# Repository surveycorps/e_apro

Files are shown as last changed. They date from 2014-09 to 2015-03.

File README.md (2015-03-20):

e_apro
======

The electrical subsytems schematics, BOM, board files
- usb_hub is a 7 port usb hub based off of TI's TUSB2077A
- audio is a usb audio codec based off the PCM2912A
- gps is a usb powered gps module based off the Jupiter SE880
- screen is a hdmi to tft screen converter using TFP401A
- motor is a motor driver with F2V converters
- powers provides power regulator based off LM3478
- apro_lib contains all the custom symbols and footprints used
- eagle contains the files for connecting the various breakoutboards

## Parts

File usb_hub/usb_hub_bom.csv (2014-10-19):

Item | Qty | Reference(s) | Value | LibPart | Footprint | Datasheet
1 | 1 | BT1 | BATTERY | device:BATTERY | Pin_Headers:Pin_Header_Straight_1x02
2 | 2 | C1, C2 | 1uF | device:C | SMD_Packages:SMD-0603
3 | 14 | C10, C11, C12, C13, C14, C15, C16, C17, C18, C20, C21, C22, C7, C8 | 22pF | device:Csmall | SMD_Packages:SMD-0603
4 | 3 | C19, C32, C6 | 4.7uF | device:C | SMD_Packages:SMD-0603
5 | 2 | C23, C24 | 22pF | device:C | SMD_Packages:SMD-0603
6 | 7 | C25, C26, C29, C33, C34, C35, C36 | 100uF | device:Csmall | SMD_Packages:SMD-1210
7 | 7 | C27, C28, C31, C37, C38, C39, C40 | .1uF | device:Csmall | SMD_Packages:SMD-0603
8 | 3 | C3, C30, C9 | .1uF | device:C | SMD_Packages:SMD-0603
9 | 2 | C4, C5 | 33pF | device:Csmall | SMD_Packages:SMD-0603
10 | 4 | D1, D2, D4, D6 | LED(G) | device:LED | LEDs:LED-0603
11 | 2 | D3, D5 | LED | device:LED | LEDs:LED-0603
12 | 1 | F1 | FUSE | device:FUSE | SMD_Packages:SMD-0603
13 | 2 | JP1, JP2 | JUMPER | device:JUMPER | Connect:GS2
14 | 8 | L1, L2, L3, L4, L5, L6, L7, L8 | FERRITE | usb_hub:FERRITE | usb_hub:FB-28F0121
15 | 1 | P1 | CONN_01X02 | conn:CONN_01X02 | Pin_Headers:Pin_Header_Straight_1x02
16 | 21 | R1, R2, R21, R22, R23, R24, R25, R26, R27, R28, R29, R3, R30, R31, R32, R33, R34, R4, R5, R6, R7 | 15k | device:R | SMD_Packages:SMD-0603
17 | 16 | R10, R11, R12, R13, R14, R15, R16, R17, R18, R19, R20, R35, R36, R38, R41, R9 | 27 | device:R | SMD_Packages:SMD-0603
18 | 6 | R37, R39, R40, R42, R44, R45 | 510 | device:R | SMD_Packages:SMD-0603
19 | 2 | R43, R8 | 1.5k | device:R | SMD_Packages:SMD-0603
20 | 2 | U1, U2 | TPS2044B | usb_hub:TPS2044B | Housings_SOIC:SOIC-16_3.9x9.9mm_Pitch1.27mm
21 | 7 | U10, U13, U14, U15, U16, U8, U9 | USB_A_FEMALE | usb_hub:USB_A_FEMALE | ab2_usb:AB2_USB_MICRO_SMD
22 | 4 | U11, U12, U6, U7 | SN75240 | usb_hub:SN75240 | usb_hub:TSSOP8
23 | 1 | U3 | TUSB2077A | usb_hub:TUSB2077A | Housings_QFP:TQFP-48_7x7mm_Pitch0.5mm
24 | 1 | U4 | TPS76333 | usb_hub:TPS76333 | SMD_Packages:SOT-23-5
25 | 1 | U5 | USB_A_MALE | usb_hub:USB_A_MALE | ab2_usb:AB2_USB_MICRO_SMD
26 | 1 | X1 | 6 MHz | device:CRYSTAL | usb_hub:FOX6MHZ

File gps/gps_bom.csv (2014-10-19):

Item | Qty | Reference(s) | Value | LibPart | Footprint | Datasheet
1 | 5 | C1, C10, C11, C3, C5 | .1uF | device:Csmall | SMD_Packages:SMD-0603
2 | 1 | C2 | 18pF | device:Csmall | SMD_Packages:SMD-0603
3 | 1 | C4 | 22pF | device:Csmall | SMD_Packages:SMD-0603
4 | 2 | C6, C7 | 1uF | device:Csmall | SMD_Packages:SMD-0603
5 | 2 | C8, C9 | 10uF | device:Csmall | SMD_Packages:SMD-0603
6 | 1 | D1 | LED(G) | device:LED | LEDs:LED-0603
7 | 7 | JP1, JP2, JP3, JP4, JP5, JP6, JP7 | JUMPER | device:JUMPER | Connect:GS2
8 | 1 | P1 | PWR | conn:CONN_01X02 | Pin_Headers:Pin_Header_Straight_1x02
9 | 1 | P2 | CTL | conn:CONN_01X02 | Pin_Headers:Pin_Header_Straight_1x02
10 | 1 | P3 | UART | conn:CONN_01X02 | Pin_Headers:Pin_Header_Straight_1x02
11 | 1 | R1 | 510 | device:R | SMD_Packages:SMD-0603
12 | 2 | R2, R3 | 100k | device:R | SMD_Packages:SMD-0603
13 | 3 | R4, R5, R7 | 10k | device:R | SMD_Packages:SMD-0603
14 | 1 | R6 | 6k | device:R | SMD_Packages:SMD-0603
15 | 1 | U1 | USB_A_FEMALE | gps-cache:USB_A_FEMALE | ab2_usb:AB2_USB_MICRO_SMD
16 | 1 | U2 | TXS0102 | gps:TXS0102 | gps:TXS0102
17 | 1 | U3 | SE880 | gps:SE880 | gps:SE880
18 | 1 | U4 | ABS25 | gps:ABS25 | gps:ABS25
19 | 1 | U5 | SGP25C | gps:SGP25C | gps:SGP25C
20 | 1 | U6 | KT2520 | gps:KT2520 | gps:KT2520
21 | 1 | U7 | TPS76333 | gps:TPS76318 | SMD_Packages:SOT-23-5
22 | 1 | U8 | TPS76318 | gps:TPS76318 | SMD_Packages:SOT-23-5

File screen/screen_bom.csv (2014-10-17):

Item | Qty | Reference(s) | Value | LibPart | Footprint | Datasheet
1 | 4 | C1, C2, C3, C4 | 22uF | device:Csmall | SMD_Packages:SMD-0603
2 | 1 | C10 | 0.22uF | device:Csmall | SMD_Packages:SMD-0603
3 | 2 | C11, C13 | 10uF | device:Csmall | SMD_Packages:SMD-1206
4 | 6 | C12, C15, C5, C6, C7, C8 | 0.1uF | device:Csmall | SMD_Packages:SMD-0603
5 | 1 | C14 | 4.7uF | device:Csmall | SMD_Packages:SMD-0603
6 | 1 | C9 | 1uF | device:Csmall | SMD_Packages:SMD-0603
7 | 1 | D1 | DIODESCH | device:DIODESCH | SCREEN:SOD323
8 | 1 | D2 | GREEN | device:LED | LEDs:LED-0603
9 | 1 | JP1 | NHD | device:JUMPER | Connect:GS2
10 | 1 | JP2 | BD | device:JUMPER | Connect:GS2
11 | 1 | JP3 | HVT | device:JUMPER | Connect:GS2
12 | 1 | JP4 | ST+ | device:JUMPER | Connect:GS2
13 | 1 | JP5 | ST- | device:JUMPER | Connect:GS2
14 | 1 | L1 | 22uH | device:INDUCTOR | SCREEN:VLCF5020
15 | 1 | P1 | CONN_01X08 | conn:CONN_01X08 | Pin_Headers:Pin_Header_Straight_1x08
16 | 2 | Q1, Q2 | N_MOS | screen:N_MOS | SMD_Packages:SOT-23
17 | 3 | R1, R2, R3 | 4.7k | screen:Rsmall | SMD_Packages:SMD-0603
18 | 4 | R10, R4, R8, R9 | 10k | screen:Rsmall | SMD_Packages:SMD-0603
19 | 1 | R11 | 1k | screen:Rsmall | SMD_Packages:SMD-0603
20 | 1 | R12 | 510R | screen:Rsmall | SMD_Packages:SMD-0603
21 | 1 | R5 | 3.32R | screen:Rsmall | SMD_Packages:SMD-0603
22 | 1 | R6 | 4.99R | screen:Rsmall | SMD_Packages:SMD-0603
23 | 1 | R7 | 10R | screen:Rsmall | SMD_Packages:SMD-0603
24 | 1 | U1 | uHDMI | screen:uHDMI | SCREEN:uHDMI
25 | 1 | U2 | TFP401A | screen:TFP401A | SCREEN:TFP401A
26 | 1 | U3 | TPS76333 | screen:TPS76333 | SMD_Packages:SOT-23-5
27 | 1 | U4 | TSP61161 | screen:TSP61161 | SCREEN:TSP61161
28 | 1 | U5 | M93C46 | usb_hub:M93C46 | SCREEN:TSSOP8
29 | 1 | U6 | HVT-4.3 | screen:HVT-4.3 | SCREEN:40_PIN
30 | 1 | U7 | NHD-5.0 | screen:NHD-5.0 | SCREEN:40_PIN
31 | 1 | USB1 | AB2_USB | ab2_usb:AB2_USB | MICRO_USB:AB2_USB_MICRO_SMD

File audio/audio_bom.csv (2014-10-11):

Item | Qty | Reference(s) | Value | LibPart | Footprint | Datasheet
1 | 6 | C1, C11, C3, C4, C5, C6 | 1uF | device:C | SMD_Packages:SMD-0603
2 | 1 | C10 | 2.2uF | device:C | SMD_Packages:SMD-0603
3 | 6 | C12, C17, C24, C25, C31, C9 | 0.1uF | device:C | SMD_Packages:SMD-0603
4 | 1 | C13 | 3u3 | device:C | SMD_Packages:SMD-0603
5 | 2 | C14, C15 | 100pF | device:C | SMD_Packages:SMD-0603
6 | 2 | C16, C8 | 22pF | device:C | SMD_Packages:SMD-0603
7 | 4 | C18, C23, C26, C32 | 10uF | device:C | SMD_Packages:SMD-0603
8 | 4 | C19, C21, C28, C30 | 1nF | device:C | SMD_Packages:SMD-0603
9 | 2 | C2, C7 | 100uF | device:C | SMD_Packages:SMD-1206
10 | 4 | C20, C22, C27, C29 | 0.47uF | device:C | SMD_Packages:SMD-0603
11 | 1 | D1 | RED | device:LED | LEDs:LED-0603
12 | 2 | D2, D3 | GREEN | device:LED | LEDs:LED-0603
13 | 2 | JP1, JP2 | JUMPER | device:JUMPER | Connect:GS2
14 | 1 | JP3 | HGS | device:JUMPER | Connect:GS2
15 | 1 | JP4 | LGS | device:JUMPER | Connect:GS2
16 | 1 | L1 | 1uH | device:INDUCTOR | SMD_Packages:SMD-0603
17 | 2 | P1, P3 | CONN_02X01 | conn:CONN_02X01 | Pin_Headers:Pin_Header_Straight_2x01
18 | 1 | P2 | CONN_01X04 | conn:CONN_01X04 | Pin_Headers:Pin_Header_Straight_1x04
19 | 3 | R1, R2, R8 | 1K5 | device:R | SMD_Packages:SMD-0603
20 | 1 | R10 | 1M | device:R | SMD_Packages:SMD-0603
21 | 1 | R11 | 510R | device:R | SMD_Packages:SMD-0603
22 | 4 | R3, R4, R7, R9 | 3K3 | device:R | SMD_Packages:SMD-0603
23 | 2 | R5, R6 | 30R | device:R | SMD_Packages:SMD-0603
24 | 1 | SP1 | RIGHT | device:SPEAKER | Connect:PINHEAD1-2
25 | 1 | SP2 | LEFT | device:SPEAKER | Connect:PINHEAD1-2
26 | 1 | U1 | PCM2912A | audio:PCM2912A | SMD_Packages:TQFP-32
27 | 1 | U2 | MIC | audio:MIC | MIC:MIC
28 | 4 | U3, U4, U6, U7 | FB | audio:FB | MIC:FB-28F0121
29 | 1 | U5 | NAU8223 | audio:NAU8223 | MIC:QFN20
30 | 1 | X1 | 6MHz | device:CRYSTAL | MIC:FOX6MHZ

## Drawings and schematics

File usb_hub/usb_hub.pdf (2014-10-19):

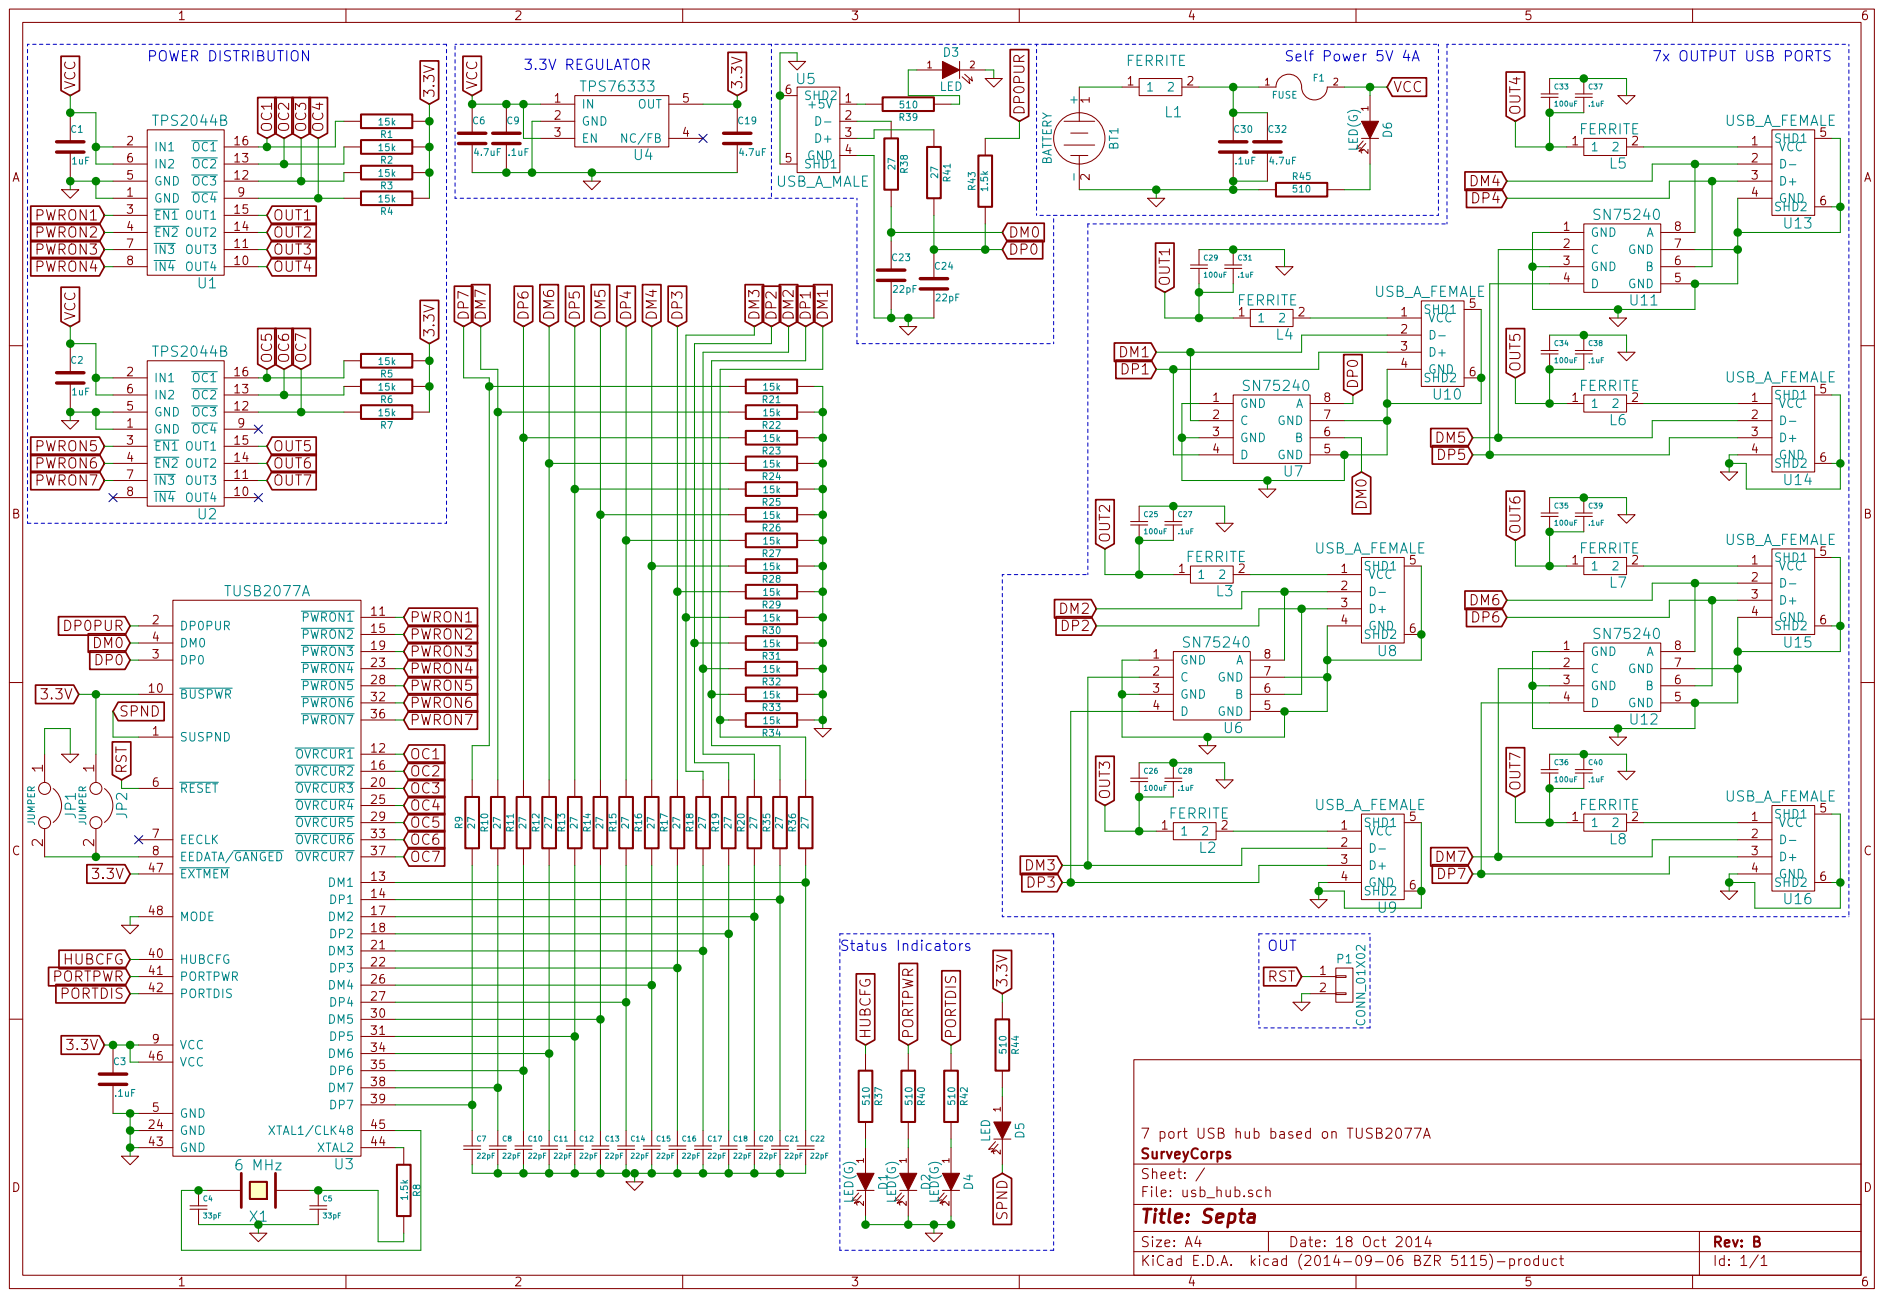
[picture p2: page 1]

1 2 D1 LED(G)1 2 D2 LED(G)1 2 D4 LED(G) 510 R37 510 R40 510 R42 HUBCFG PORTPWR PORTDIS

7 port USB hub based on TUSB2077A
File: usb_hub.sch Sheet: / SurveyCorps

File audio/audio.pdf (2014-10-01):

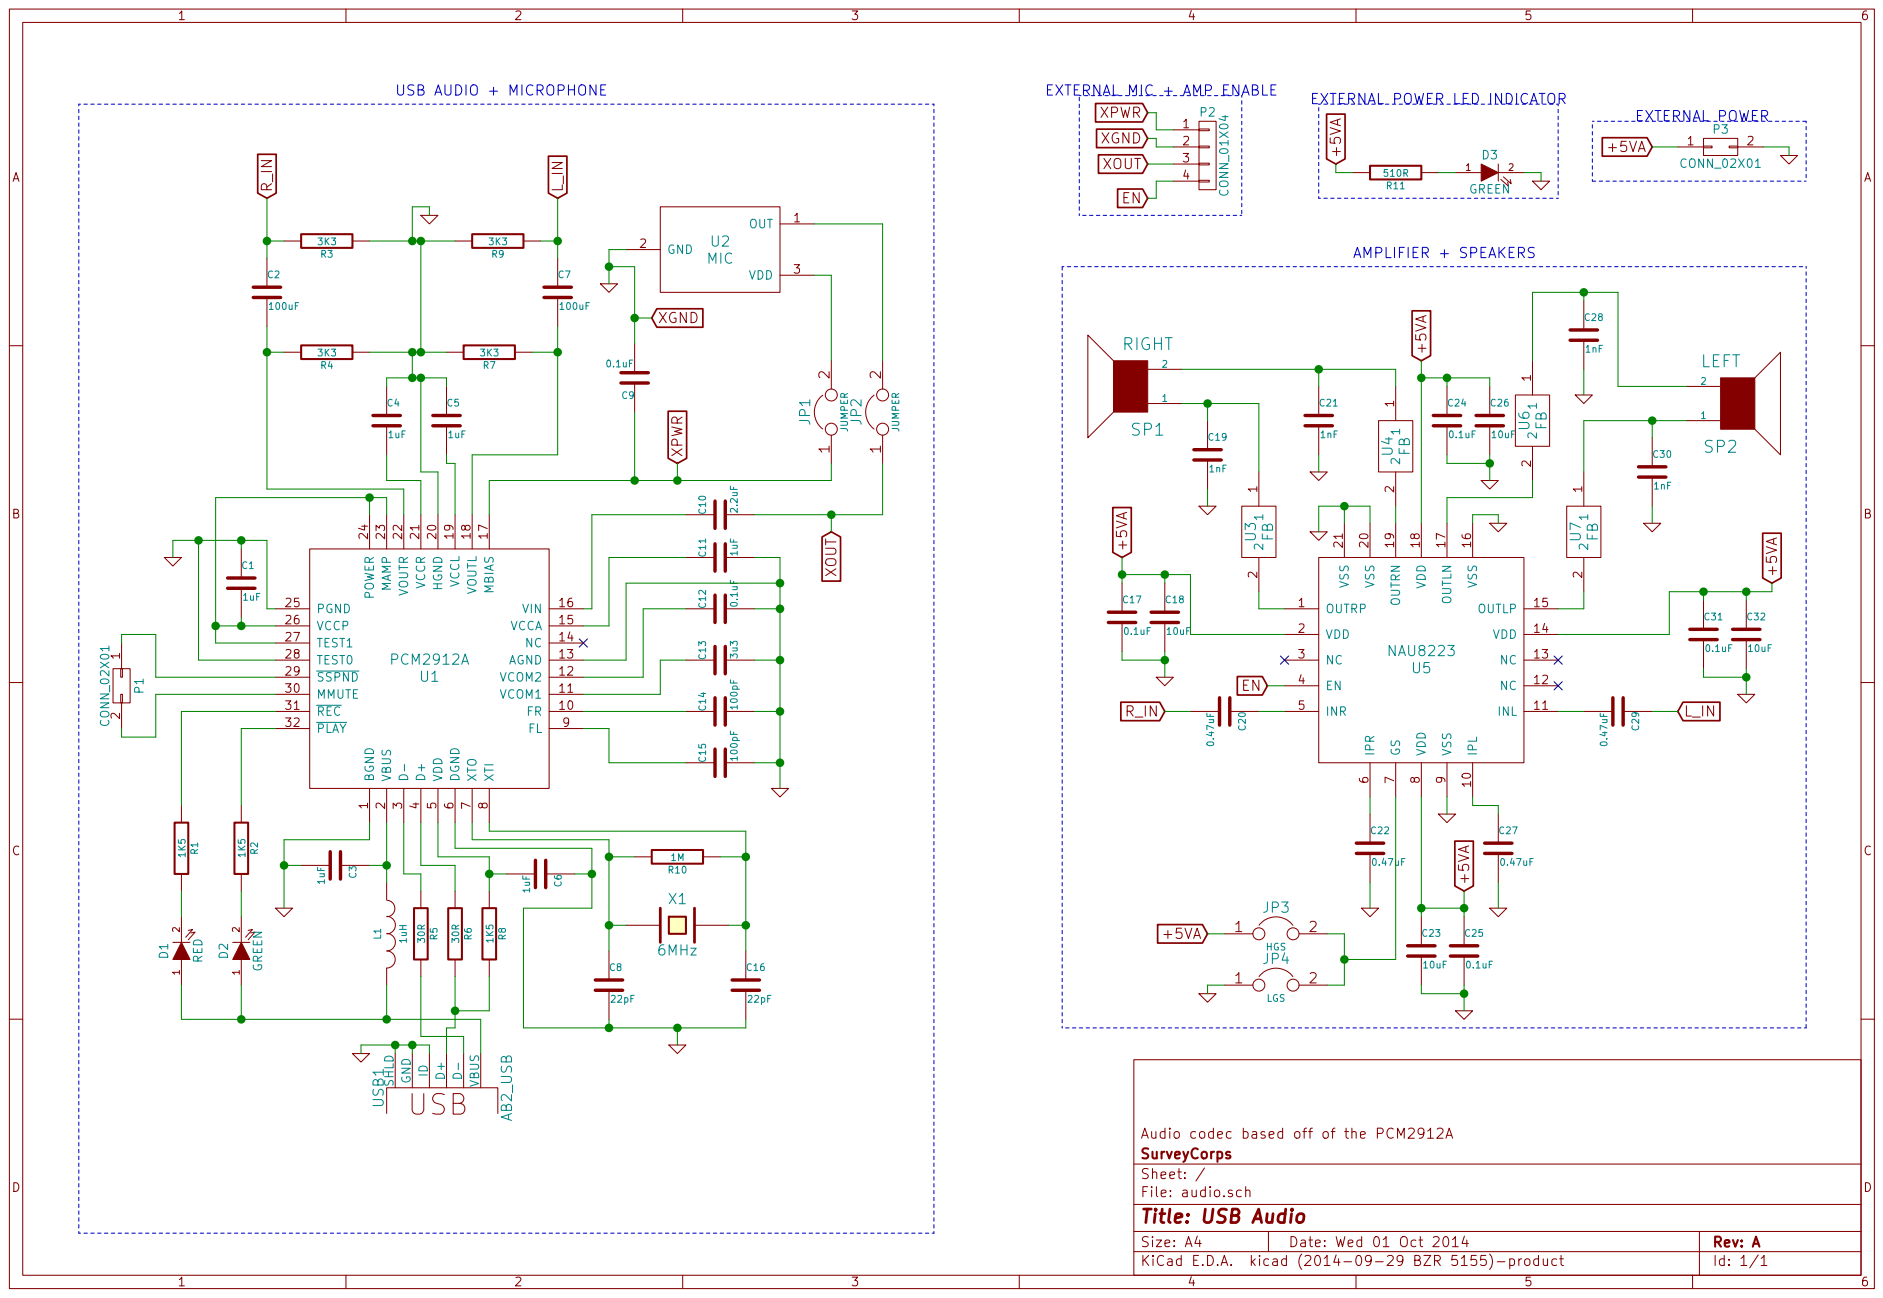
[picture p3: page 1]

EXTERNAL MIC + AMP ENABLE

510R EXTERNAL POWER LED INDICATOR

File: audio.sch Sheet: / SurveyCorps Audio codec based off of the PCM2912A

Id: 1/1 Title: USB Audio

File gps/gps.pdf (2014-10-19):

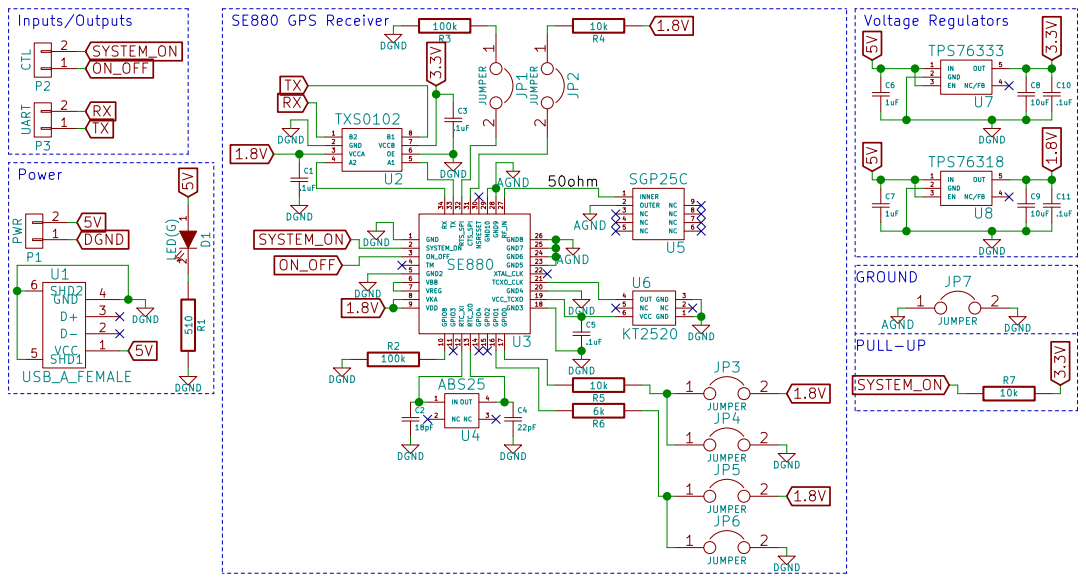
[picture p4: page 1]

GPS Receiver Based on the Jupiter SE880
File: gps.sch Sheet: / SurveyCorps

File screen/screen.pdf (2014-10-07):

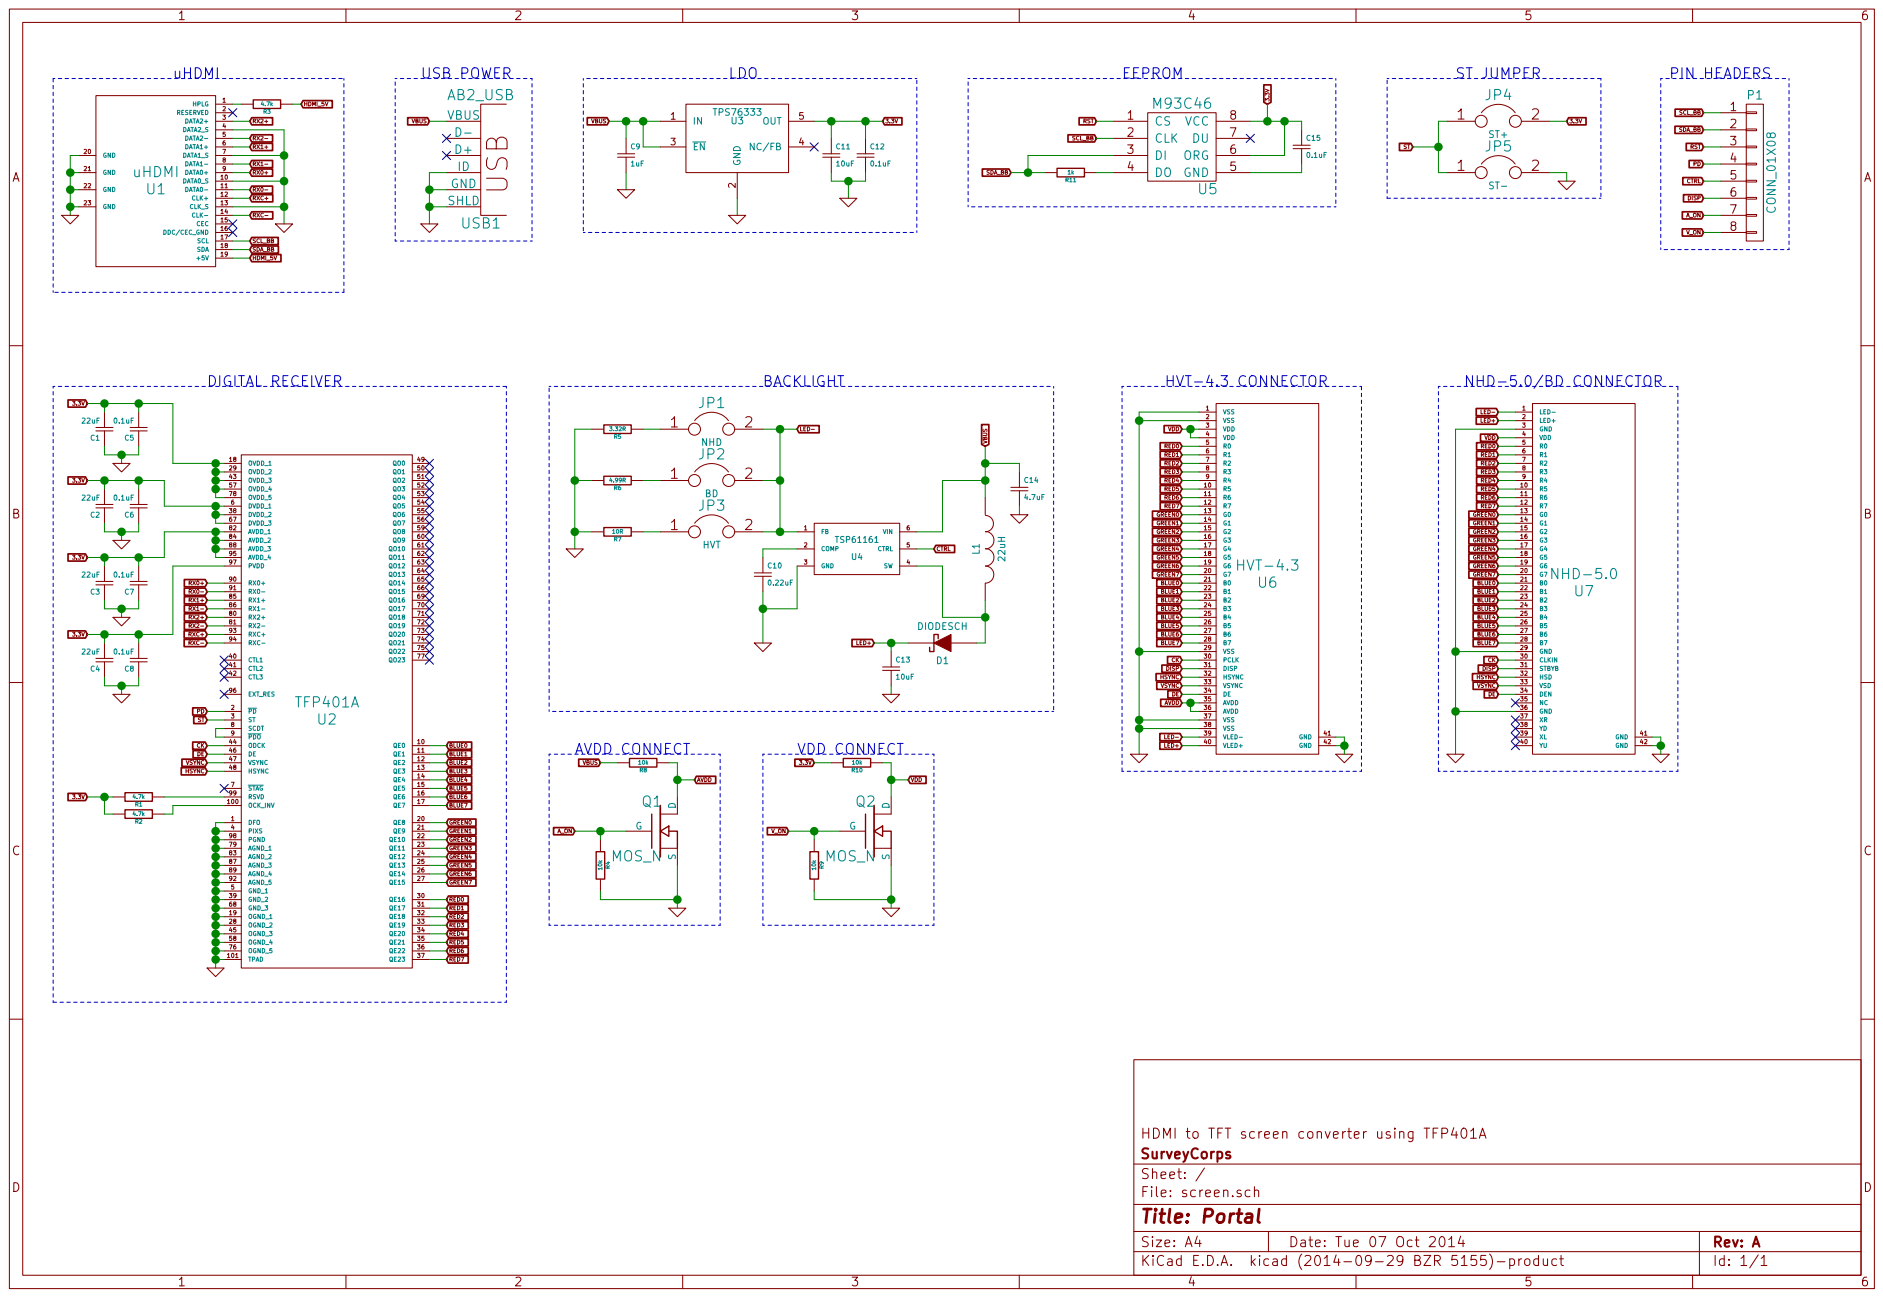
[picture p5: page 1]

2 EN 3 NC/FB 4 OUT 5 U3 TPS76333

HDMI to TFT screen converter using TFP401A
Id: 1/1 Title: Portal File: screen.sch Sheet: / SurveyCorps

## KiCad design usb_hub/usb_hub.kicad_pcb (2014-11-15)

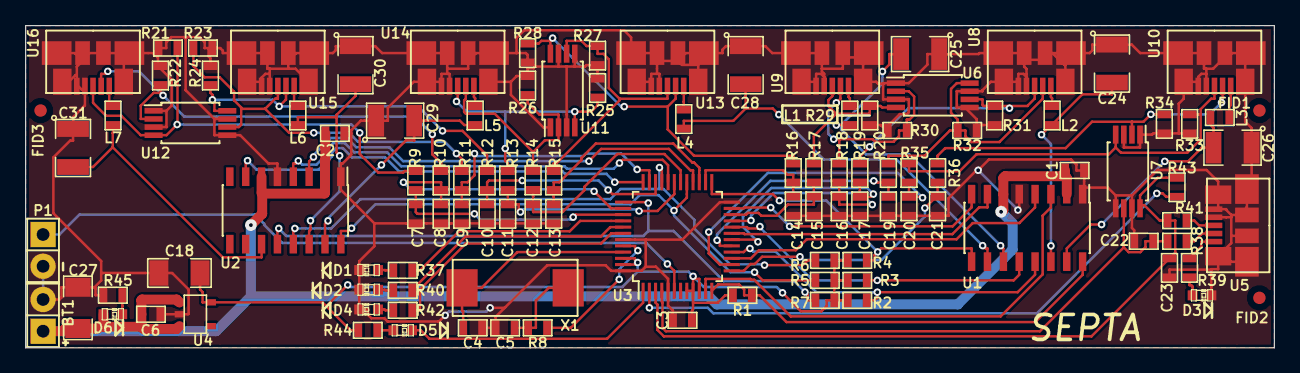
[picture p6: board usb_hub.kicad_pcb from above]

Board: 2 copper layers, 100.0 x 25.8 mm, 111 parts (0 on the bottom side), 79 nets.

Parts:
BT1: BATTERY; Pin_Header_Straight_1x02
C1, C2, C6: 1uF; SMD-0603
C3: .1uF; SMD-0603
C4, C5: 33pF; SMD-0603
C7, C8, C9, C10, C11, C12, C13, C14, C15, C16, C17, C19, C20, C21, C22, C23: 22pF; SMD-0603
C18, C27: 10uF; SMD-1206
C24, C25, C26, C28, C29, C30, C31: 100uF; SMD-1210
D1, D2, D3, D4, D5, D6: LED; LED-0603
FID1, FID2, FID3: VAL**; SBA_FID
L1, L2, L3, L4, L5, L6, L7: FERRITE; SMD-0603
P1: CONN_01X02; Pin_Header_Straight_1x02
R1, R2, R3, R4, R5, R6, R7, R21, R22, R23, R24, R25, R26, R27, R28, R29, R30, R31, R32, R33, R34: 15k; SMD-0603
R8, R43: 1.5k; SMD-0603
R9, R10, R11, R12, R13, R14, R15, R16, R17, R18, R19, R20, R35, R36, R38, R41: 30; SMD-0603
R37, R39, R40, R42, R44, R45: 1k; SMD-0603
U1, U2: TPS2044B; SOIC-16_3.9x9.9mm_Pitch1.27mm
U3: TUSB2077A; TQFP-48_7x7mm_Pitch0.5mm
U4: TPS76333; SOT-23-5
U5: USB_A_MALE; MICRO_USB
U6, U7, U11, U12: SN75240; TSSOP-8_4.4x3mm_Pitch0.65mm
U8, U9, U10, U13, U14, U15, U16: USB_MICRO_OUT; MICRO_USB
X1: 6 MHz; FOX6MHZ

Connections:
3.3V: C3.1, C18.1, R1.1, R2.1, R3.1, R4.1, R5.1, R6.1, R7.1, R44.1, U3.8, U3.9, U3.10, U3.46, U3.47, U4.5
DM0: C22.1, R38.1, U3.4, U7.6
DM1: R34.2, R36.2, U7.2, U10.2
DM2: R20.2, R32.2, U6.8, U8.2
DM3: R18.2, R30.2, U6.2, U9.2
DM4: R16.2, R28.2, U11.8, U13.2
DM5: R14.2, R26.2, U11.2, U14.2
DM6: R12.2, R24.2, U12.8, U15.2
DM7: R10.2, R22.2, U12.2, U16.2
DP0: C23.1, R41.1, R43.2, U3.3, U7.8
DP0PUR: R43.1, U3.2
DP1: R33.2, R35.2, U7.4, U10.3
DP2: R19.2, R31.2, U6.6, U8.3
DP3: R17.2, R29.2, U6.4, U9.3
DP4: R15.2, R27.2, U11.6, U13.3
DP5: R13.2, R25.2, U11.4, U14.3
DP6: R11.2, R23.2, U12.6, U15.3
DP7: R9.2, R21.2, U12.4, U16.3
GND: BT1.2, C1.2, C2.2, C3.2, C4.2, C5.2, C6.2, C7.2, C8.2, C9.2, C10.2, C11.2, C12.2, C13.2, C14.2, C15.2, C16.2, C17.2, C18.2, C19.2, C20.2, C21.2, C22.2, C23.2, C24.1, C25.1, C26.1, C27.2, C28.1, C29.1, C30.1, C31.1, D1.2, D2.2, D3.2, D4.2, P1.2, R21.1, R22.1, R23.1, R24.1, R25.1, R26.1, R27.1, R28.1, R29.1, R30.1, R31.1, R32.1, R33.1, R34.1, R45.1, U1.1, U1.5, U2.1, U2.5, U3.5, U3.24, U3.43, U3.48, U4.2, U5.4, U5.5, U5.6, U6.1, U6.3, U6.5, U6.7, U7.1, U7.3, U7.5, U7.7, U8.4, U8.5, U8.6, U9.4, U9.5, U9.6, U10.4, U10.5, U10.6, U11.1, U11.3, U11.5, U11.7, U12.1, U12.3, U12.5, U12.7, U13.4, U13.5, U13.6, U14.4, U14.5, U14.6, U15.4, U15.5, U15.6, U16.4, U16.5, U16.6
HUBCFG: R37.1, U3.40
unnamed: C4.1, U3.45, X1.2
unnamed: C5.1, R8.2, X1.1
unnamed: C7.1, R9.1, U3.39
unnamed: C8.1, R10.1, U3.38
unnamed: C9.1, R11.1, U3.35
unnamed: C10.1, R12.1, U3.34
unnamed: C11.1, R13.1, U3.31
unnamed: C12.1, R14.1, U3.30
unnamed: C13.1, R15.1, U3.27
unnamed: C14.1, R16.1, U3.26
unnamed: C15.1, R17.1, U3.22
unnamed: C16.1, R18.1, U3.21
unnamed: C17.1, R19.1, U3.18
unnamed: C19.1, R20.1, U3.17
unnamed: C20.1, R35.1, U3.14
unnamed: C21.1, R36.1, U3.13
unnamed: D1.1, R37.2
unnamed: D2.1, R40.2
unnamed: D3.1, R39.1
unnamed: D4.1, R42.2
unnamed: D5.1, R44.2
unnamed: D6.2, R45.2
unnamed: L1.2, U9.1
unnamed: L2.2, U8.1
unnamed: L3.2, U10.1
unnamed: L4.2, U13.1
unnamed: L5.2, U14.1
unnamed: L6.2, U15.1
unnamed: L7.2, U16.1
unnamed: R8.1, U3.44
unnamed: R38.2, U5.2
unnamed: R39.2, U5.1
unnamed: R41.2, U5.3
OC1: R1.2, U1.16, U3.12
OC2: R2.2, U1.13, U3.16
OC3: R3.2, U1.12, U3.20
OC4: R4.2, U1.9, U3.25
OC5: R5.2, U2.16, U3.29
OC6: R6.2, U2.13, U3.33
OC7: R7.2, U2.12, U3.37
OUT1: C26.2, L3.1, U1.15
OUT2: C24.2, L2.1, U1.14
OUT3: C25.2, L1.1, U1.11
OUT4: C28.2, L4.1, U1.10
OUT5: C29.2, L5.1, U2.15
OUT6: C30.2, L6.1, U2.14
OUT7: C31.2, L7.1, U2.11
PORTDIS: R42.1, U3.42
PORTPWR: R40.1, U3.41
PWRON1: U1.3, U3.11
PWRON2: U1.4, U3.15
PWRON3: U1.7, U3.19
PWRON4: U1.8, U3.23
PWRON5: U2.3, U3.28
PWRON6: U2.4, U3.32
PWRON7: U2.7, U3.36
RST: P1.1, U3.6
SPND: D5.2, U3.1
VCC: BT1.1, C1.1, C2.1, C6.1, C27.1, D6.1, U1.2, U1.6, U2.2, U2.6, U4.1, U4.3

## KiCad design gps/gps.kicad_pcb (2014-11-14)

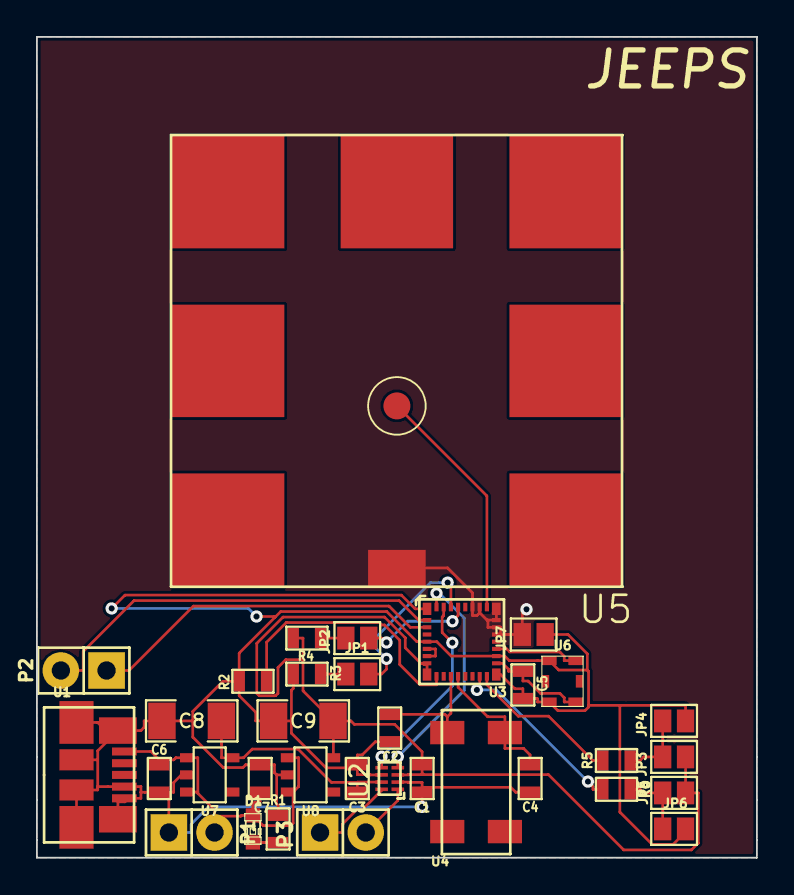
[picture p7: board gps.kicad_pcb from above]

Board: 2 copper layers, 40.0 x 45.6 mm, 34 parts (0 on the bottom side), 27 nets.

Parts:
C1, C3, C5: .1uF; SMD-0603
C2: 18pF; SMD-0603
C4: 22pF; SMD-0603
C6, C7: 1uF; SMD-0603
C8, C9: 10uF; SMD-1206
D1: LED; LED-0603
JP1, JP2, JP3, JP4, JP5, JP6, JP7: JUMPER; GS2
P1: PWR; Pin_Header_Straight_1x02
P2: CTL; Pin_Header_Straight_1x02
P3: UART; Pin_Header_Straight_1x02
R1: 1k; SMD-0603
R2, R3: 100k; SMD-0603
R4, R5: 10k; SMD-0603
R6: 6k; SMD-0603
U1: USB_A_FEMALE; MICRO_USB
U2: TXS0102
U3: SE880
U4: ABS25
U5: SGP25C
U6: KT2520
U7: TPS76333; SOT-23-5
U8: TPS76318; SOT-23-5

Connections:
1.8V: C1.1, C9.1, JP3.2, JP5.2, R4.1, U2.3, U3.8, U3.9, U8.5
3.3V: C3.1, C8.1, U2.7, U7.5
5V: C6.1, C7.1, D1.1, P1.2, U1.1, U7.1, U7.3, U8.1, U8.3
/50ohm: U3.27, U5.1
AGND: JP7.1, U3.23, U3.24, U3.25, U3.26, U3.28, U3.29, U5.2
DGND: C1.2, C2.2, C3.2, C4.2, C5.2, C6.2, C7.2, C8.2, C9.2, JP4.2, JP6.2, JP7.2, P1.1, R1.2, R2.2, R3.2, U1.4, U1.5, U1.6, U2.2, U2.6, U3.1, U3.5, U3.18, U3.20, U6.1, U6.3, U7.2, U8.2
unnamed: C2.1, U3.12, U4.1
unnamed: C4.1, U3.13, U4.4
unnamed: C5.1, U3.19, U6.6
unnamed: D1.2, R1.1
unnamed: JP1.1, R3.1
unnamed: JP1.2, U3.32
unnamed: JP2.1, R4.2
unnamed: JP2.2, U3.31
unnamed: JP3.1, JP4.1, R5.1
unnamed: JP5.1, JP6.1, R6.1
unnamed: R2.1, U3.10
unnamed: R5.2, U3.17
unnamed: R6.2, U3.16
unnamed: U2.4, U3.34
unnamed: U2.5, U3.33
unnamed: U3.6, U3.7
unnamed: U3.21, U6.4
ON_OFF: P2.1, U3.3
RX: P3.2, U2.1
SYSTEM_ON: P2.2, U3.2
TX: P3.1, U2.8

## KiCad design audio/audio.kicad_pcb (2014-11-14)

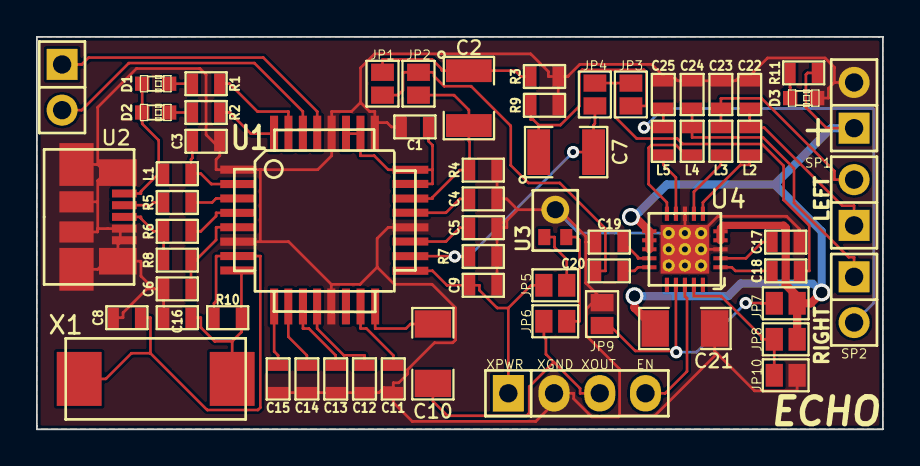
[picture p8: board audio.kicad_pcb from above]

Board: 2 copper layers, 47.0 x 21.8 mm, 64 parts (0 on the bottom side), 52 nets.

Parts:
C1, C3, C4, C5, C6, C11, C17, C18, C19, C20: 1uF; SMD-0603
C2, C7: 100uF; SMD-1210
C8, C16: 33pF; SMD-0603
C9, C12: .1uF; SMD-0603
C10, C21: 10uF; SMD-1206
C13: 3.3uF; SMD-0603
C14, C15: 100pF; SMD-0603
C22, C23, C24, C25: 1nF; SMD-0603
D1, D2, D3: GREEN; LED-0603
JP1, JP2, JP3, JP4, JP5, JP6, JP7, JP8, JP9, JP10: JUMPER; GS2
L1: 1uH; SMD-0603
L2, L3, L4, L5: FERRITE; SMD-0603
P1, P3: CONN_02X01; Pin_Header_Straight_2x01
P2: CONN_01X04; Pin_Header_Straight_1x04
R1, R2, R11: 1k; SMD-0603
R3, R4, R7, R9: 3K3; SMD-0603
R5, R6: 30R; SMD-0603
R8: 1K5; SMD-0603
R10: 1M; SMD-0603
SP1, SP2: SPEAKER; Pin_Header_Straight_2x01
U1: PCM2912A; TQFP-32
U2: USB_A_MALE; MICRO_USB
U3: MIC
U4: TPA2017D2
X1: 6MHz; FOX6MHZ

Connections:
+5VA: C21.2, JP7.1, JP8.1, P3.1, R11.2, U4.4, U4.5, U4.11, U4.12, U4.13
EN: P2.4, U4.18
L_IN: C18.2, JP3.1, JP4.2
unnamed: C1.1, U1.23, U1.24, U1.26, U1.27
unnamed: C2.1, JP1.2, R3.2
unnamed: C2.2, JP2.1, R4.2, U1.22
unnamed: C3.1, L1.1, U1.2
unnamed: C4.2, U1.21
unnamed: C5.2, U1.19
unnamed: C6.2, R8.1, U1.5
unnamed: C7.1, JP4.1, R9.1
unnamed: C7.2, JP3.2, R7.1, U1.18
unnamed: C8.1, R10.2, U1.7, X1.1
unnamed: C10.2, U1.16
unnamed: C11.1, U1.15
unnamed: C12.2, U1.12
unnamed: C13.2, U1.11
unnamed: C14.2, U1.10
unnamed: C15.2, U1.9
unnamed: C16.1, R10.1, U1.8, X1.2
unnamed: C17.1, U4.2
unnamed: C18.1, U4.1
unnamed: C19.1, U4.14
unnamed: C20.1, U4.15
unnamed: C22.2, L2.2, SP1.1
unnamed: C23.2, L3.2, SP1.2
unnamed: C24.2, L4.2, SP2.1
unnamed: C25.2, L5.2, SP2.2
unnamed: D1.1, D2.1, L1.2, U2.1
unnamed: D1.2, R1.2
unnamed: D2.2, R2.2
unnamed: D3.1, R11.1
unnamed: JP5.2, U3.3
unnamed: JP6.2, U3.1
unnamed: JP7.2, JP9.2, U4.17
unnamed: JP8.2, JP10.2, U4.19
unnamed: L2.1, U4.6
unnamed: L3.1, U4.7
unnamed: L4.1, U4.10
unnamed: L5.1, U4.9
unnamed: P1.1, U1.29
unnamed: P1.2, U1.30
unnamed: R1.1, U1.31
unnamed: R2.1, U1.32
unnamed: R5.1, U1.3
unnamed: R5.2, U2.2
unnamed: R6.1, U1.4
unnamed: R6.2, R8.2, U2.3
R_IN: C20.2, JP1.1, JP2.2
XGND: C1.2, C3.2, C4.1, C5.1, C6.1, C8.2, C9.1, C11.2, C12.1, C13.1, C14.1, C15.1, C16.2, C17.2, C19.2, C21.1, C22.1, C23.1, C24.1, C25.1, D3.2, JP9.1, JP10.1, P2.2, P3.2, R3.1, R4.1, R7.2, R9.2, U1.1, U1.6, U1.13, U1.20, U1.25, U1.28, U2.4, U2.5, U2.6, U3.2, U4.3, U4.8, U4.21
XOUT: C10.1, JP6.1, P2.3
XPWR: C9.2, JP5.1, P2.1, U1.17

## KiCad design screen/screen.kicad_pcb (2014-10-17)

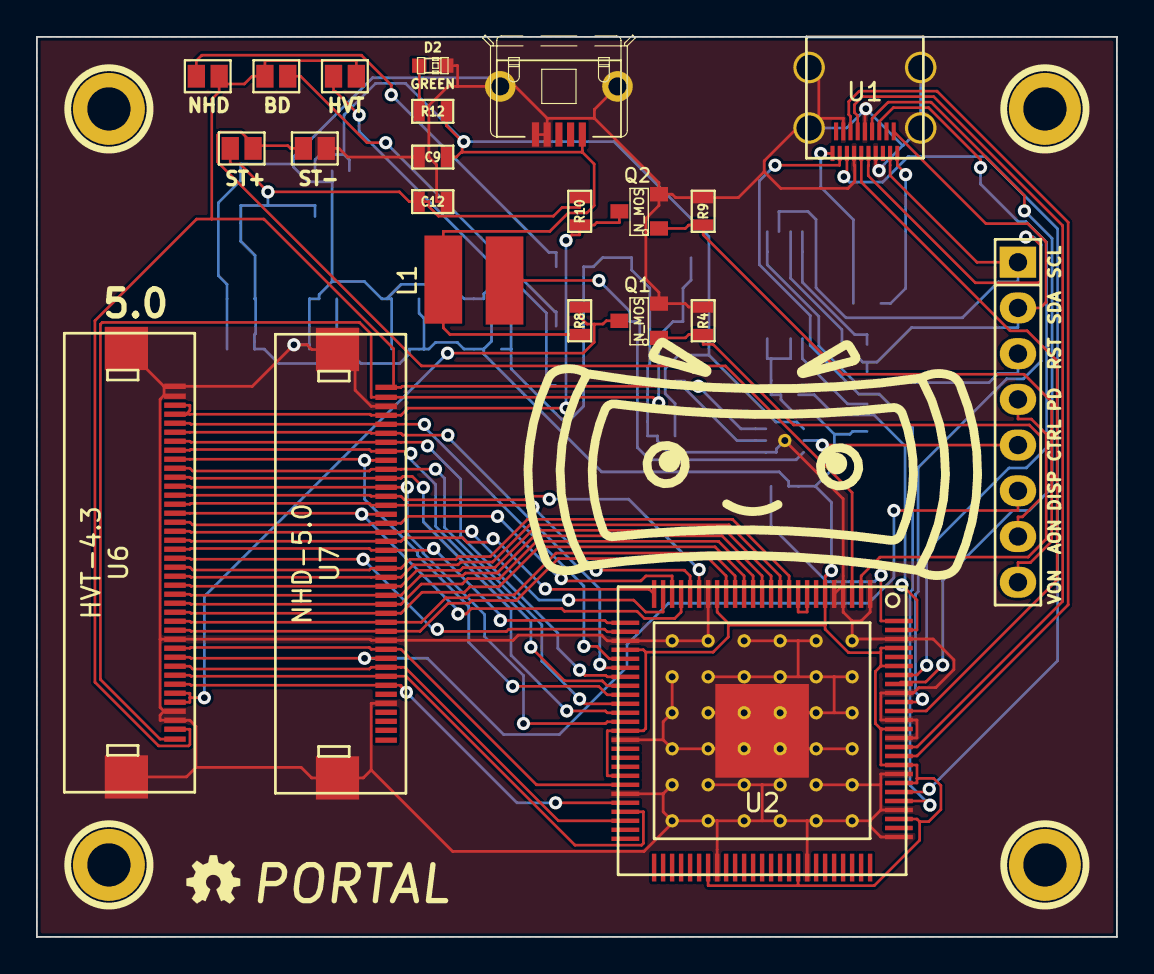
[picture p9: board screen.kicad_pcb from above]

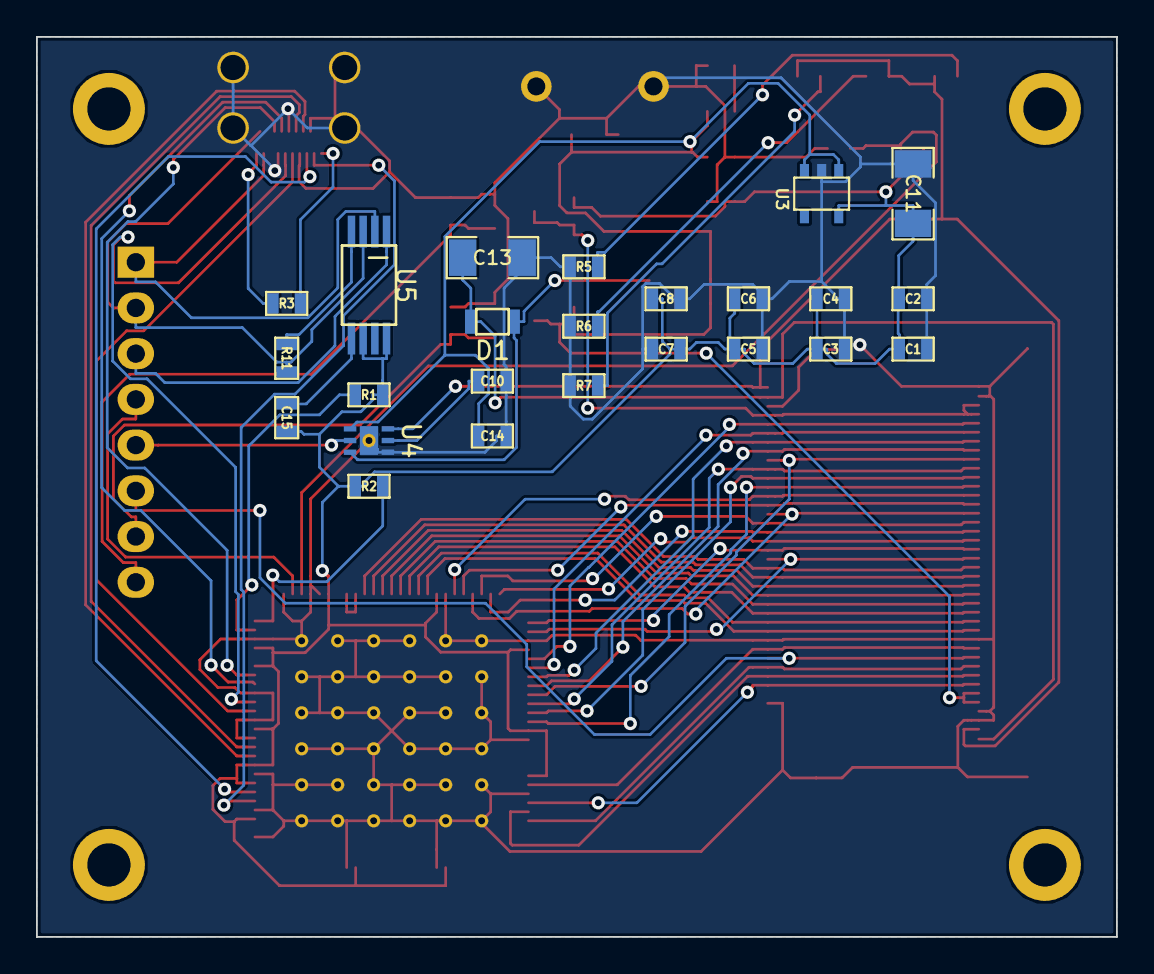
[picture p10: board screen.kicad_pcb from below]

Board: 2 copper layers, 60.0 x 50.0 mm, 52 parts (24 on the bottom side), 65 nets.

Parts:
1PIN, 2PIN, 3PIN, 4PIN: P***; 1pin
C1, C2, C3, C4: 22uF; SMD-0603
C5, C6, C7, C8, C12, C15: 0.1uF; SMD-0603
C9: 1uF; SMD-0603
C10: 0.22uF; SMD-0603
C11, C13: 10uF; SMD-1206
C14: 4.7uF; SMD-0603
D1: DIODESCH; SOD323
D2: GREEN; LED-0603
G1: LOGO; OSLOGO
G2: LOGO
JP1: NHD; GS2
JP2: BD; GS2
JP3: HVT; GS2
JP4: ST+; GS2
JP5: ST-; GS2
L1: 22uH; VLCF5020
P1: CONN_01X08; Pin_Header_Straight_1x08
Q1, Q2: N_MOS; SOT-23
R1, R2, R3: 4.7k; SMD-0603
R4, R8, R9, R10: 10k; SMD-0603
R5: 3.32R; SMD-0603
R6: 4.99R; SMD-0603
R7: 10R; SMD-0603
R11: 1k; SMD-0603
R12: 510R; SMD-0603
U1: uHDMI
U2: TFP401A
U3: TPS76333; SOT-23-5
U4: TSP61161
U5: M93C46; TSSOP8
U6: HVT-4.3; 40_PIN
U7: NHD-5.0; 40_PIN
USB1: AB2_USB; AB2_USB_MICRO_SMD

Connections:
3.3V: C1.2, C2.2, C3.2, C4.2, C5.2, C6.2, C7.2, C8.2, C11.1, C12.1, C15.1, JP4.2, R1.2, R2.2, R10.2, U2.6, U2.18, U2.29, U2.38, U2.43, U2.57, U2.67, U2.78, U2.82, U2.84, U2.88, U2.95, U2.97, U3.5, U5.6, U5.8
AVDD: Q1.3, R8.1, U6.35, U6.36
A_ON: P1.7, Q1.1, R4.1
BLUE0: U2.10, U6.21, U7.21
BLUE1: U2.11, U6.22, U7.22
BLUE2: U2.12, U6.23, U7.23
BLUE3: U2.13, U6.24, U7.24
BLUE4: U2.14, U6.25, U7.25
BLUE5: U2.15, U6.26, U7.26
BLUE6: U2.16, U6.27, U7.27
BLUE7: U2.17, U6.28, U7.28
CK: U2.44, U6.30, U7.30
CTRL: P1.5, U4.5
DE: U2.46, U6.34, U7.34
DISP: P1.6, U6.31, U7.31
GND: C1.1, C2.1, C3.1, C4.1, C5.1, C6.1, C7.1, C8.1, C9.2, C10.2, C11.2, C12.2, C13.2, C14.2, D2.2, JP5.2, Q1.2, Q2.2, R4.2, R5.2, R6.2, R7.2, R9.2, U1.4, U1.7, U1.10, U1.13, U1.20, U1.21, U1.22, U1.23, U2.1, U2.4, U2.5, U2.19, U2.28, U2.39, U2.45, U2.58, U2.68, U2.76, U2.79, U2.83, U2.87, U2.89, U2.92, U2.98, U2.101, U3.2, U4.3, U4.7, U6.1, U6.2, U6.29, U6.37, U6.38, U6.41, U6.42, U7.3, U7.29, U7.36, U7.41, U7.42, USB1.4, USB1.5, USB1.6
GREEN0: U2.20, U6.13, U7.13
GREEN1: U2.21, U6.14, U7.14
GREEN2: U2.22, U6.15, U7.15
GREEN3: U2.23, U6.16, U7.16
GREEN4: U2.24, U6.17, U7.17
GREEN5: U2.25, U6.18, U7.18
GREEN6: U2.26, U6.19, U7.19
GREEN7: U2.27, U6.20, U7.20
HDMI_5V: R3.1, U1.19
HSYNC: U2.48, U6.32, U7.32
LED+: C13.1, D1.2, U6.40, U7.2
LED-: JP1.2, JP2.2, JP3.2, U4.1, U6.39, U7.1
unnamed: C10.1, U4.2
unnamed: C15.2, U5.5
unnamed: D1.1, L1.2, U4.4
unnamed: D2.1, R12.1
unnamed: JP1.1, R5.1
unnamed: JP2.1, R6.1
unnamed: JP3.1, R7.1
unnamed: R1.1, U2.99
unnamed: R2.1, U2.100
unnamed: R3.2, U1.1
unnamed: R11.1, U5.4
unnamed: U2.8, U2.9
PD: P1.4, U2.2
RED0: U2.30, U6.5, U7.5
RED1: U2.31, U6.6, U7.6
RED2: U2.32, U6.7, U7.7
RED3: U2.33, U6.8, U7.8
RED4: U2.34, U6.9, U7.9
RED5: U2.35, U6.10, U7.10
RED6: U2.36, U6.11, U7.11
RED7: U2.37, U6.12, U7.12
RST: P1.3, U5.1
RX0+: U1.9, U2.90
RX0-: U1.11, U2.91
RX1+: U1.6, U2.85
RX1-: U1.8, U2.86
RX2+: U1.3, U2.80
RX2-: U1.5, U2.81
RXC+: U1.12, U2.93
RXC-: U1.14, U2.94
SCL_BB: P1.1, U1.17, U5.2
SDA_BB: P1.2, R11.2, U1.18, U5.3
ST: JP4.1, JP5.1, U2.3
VBUS: C9.1, C14.1, L1.1, R8.2, R12.2, U3.1, U3.3, U4.6, USB1.1
VDD: Q2.3, R10.1, U6.3, U6.4, U7.4
VSYNC: U2.47, U6.33, U7.33
V_ON: P1.8, Q2.1, R9.1

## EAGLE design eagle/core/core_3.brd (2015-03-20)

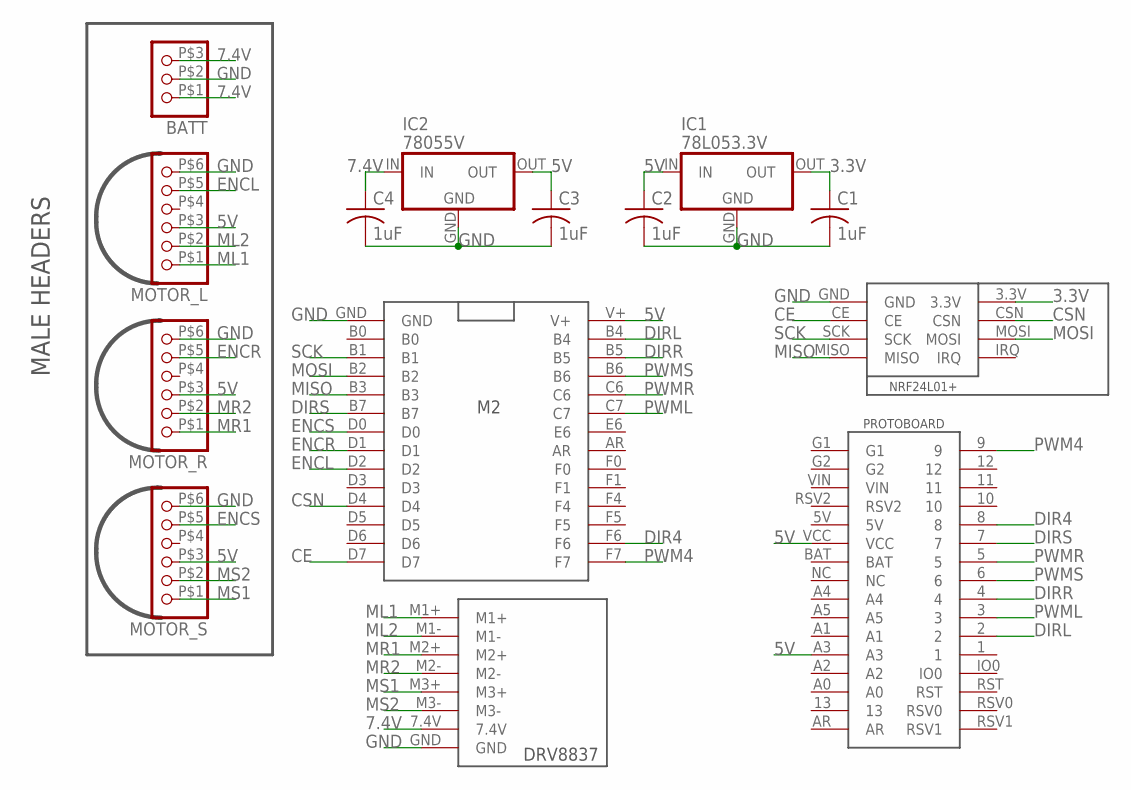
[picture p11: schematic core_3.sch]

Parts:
BATT: PINHD-1X3SMD; 1X3/90SMD
C1, C2, C3, C4: 1uF; C025-030X050
IC1: 78L053.3V; TO92
IC2: 78055V; TO220H
MOTOR_L: PINHD-1X6SMD; 1X6/90SMD
MOTOR_R: PINHD-1X6SMD; 1X6/90SMD
MOTOR_S: PINHD-1X6SMD; 1X6/90SMD
U$1: NRF24L01
U$2: M2
U$3: PROTOBOARDSMD; PROTOSMD
U$4: DRV8837

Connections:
3.3V: C1.1, IC1.OUT, U$1.3.3V
5V: C2.1, C3.1, IC1.IN, IC2.OUT, MOTOR_L.P$3 (3), MOTOR_R.P$3 (3), MOTOR_S.P$3 (3), U$2.V+, U$3.A3, U$3.VCC
7.4V: BATT.P$1 (1), BATT.P$3 (3), C4.1, IC2.IN, U$4.7.4V
CE: U$1.CE, U$2.D7
CSN: U$1.CSN, U$2.D4
DIR4: U$2.F6, U$3.8
DIRL: U$2.B4, U$3.2
DIRR: U$2.B5, U$3.4
DIRS: U$2.B7, U$3.7
ENCL: MOTOR_L.P$5 (5), U$2.D2
ENCR: MOTOR_R.P$5 (5), U$2.D1
ENCS: MOTOR_S.P$5 (5), U$2.D0
GND: BATT.P$2 (2), C1.2, C2.2, C3.2, C4.2, IC1.GND, IC2.GND, MOTOR_L.P$6 (6), MOTOR_R.P$6 (6), MOTOR_S.P$6 (6), U$1.GND, U$2.GND, U$4.GND
MISO: U$1.MISO, U$2.B3
ML1: MOTOR_L.P$1 (1), U$4.M1+
ML2: MOTOR_L.P$2 (2), U$4.M1-
MOSI: U$1.MOSI, U$2.B2
MR1: MOTOR_R.P$1 (1), U$4.M2+
MR2: MOTOR_R.P$2 (2), U$4.M2-
MS1: MOTOR_S.P$1 (1), U$4.M3+
MS2: MOTOR_S.P$2 (2), U$4.M3-
PWM4: U$2.F7, U$3.9
PWML: U$2.C7, U$3.3
PWMR: U$2.C6, U$3.5
PWMS: U$2.B6, U$3.6
SCK: U$1.SCK, U$2.B1

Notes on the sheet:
MALE HEADERS

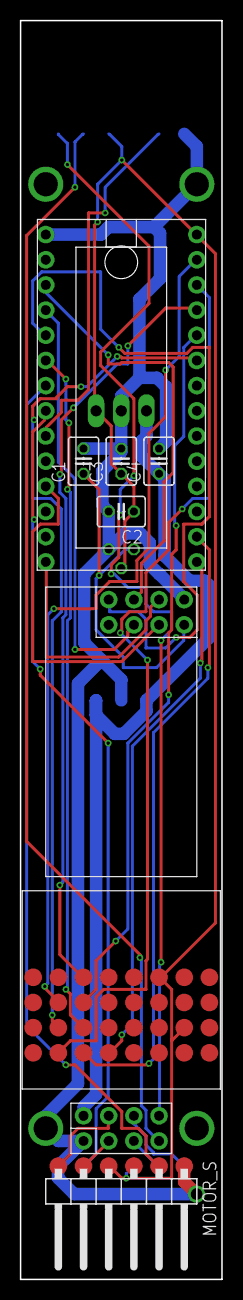
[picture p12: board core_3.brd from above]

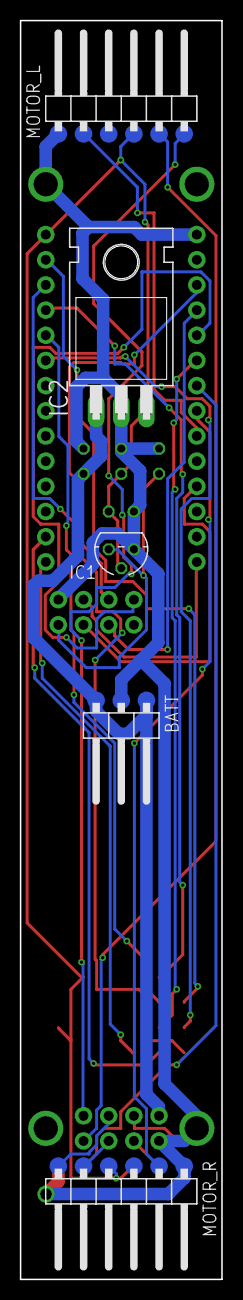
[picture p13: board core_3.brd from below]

Board: 2 copper layers, 20.3 x 127.0 mm, 14 parts (5 on the bottom side), 26 nets.

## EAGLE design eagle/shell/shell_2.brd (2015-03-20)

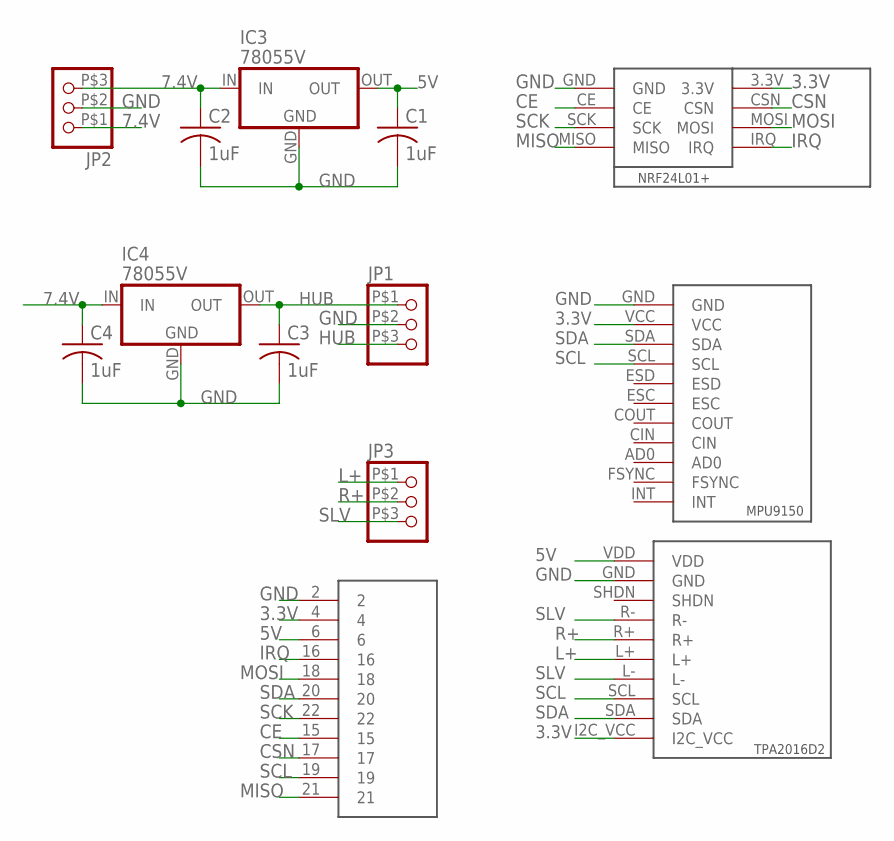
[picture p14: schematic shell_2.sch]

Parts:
C1, C2, C3, C4: 1uF; C050-024X044
IC3, IC4: 78055V; TO220H
JP1, JP2, JP3: PINHD-1X3SMD; 1X3/90SMD
JP4: PINHD-1X11SMD; 1X11/90_2
U$1: MPU9150
U$2: NRF24L01
U$3: TPA2016D2

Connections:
3.3V: JP4.4, U$1.VCC, U$2.3.3V, U$3.I2C_VCC
5V: C1.1, IC3.OUT, JP4.6, U$3.VDD
7.4V: C2.1, C4.1, IC3.IN, IC4.IN, JP2.P$1 (1), JP2.P$3 (3)
CE: JP4.15, U$2.CE
CSN: JP4.17, U$2.CSN
GND: C1.2, C2.2, C3.2, C4.2, IC3.GND, IC4.GND, JP1.P$2 (2), JP2.P$2 (2), JP4.2, U$1.GND, U$2.GND, U$3.GND
HUB: C3.1, IC4.OUT, JP1.P$1 (1), JP1.P$3 (3)
IRQ: JP4.16, U$2.IRQ
L+: JP3.P$1 (1), U$3.L+
MISO: JP4.21, U$2.MISO
MOSI: JP4.18, U$2.MOSI
R+: JP3.P$2 (2), U$3.R+
SCK: JP4.22, U$2.SCK
SCL: JP4.19, U$1.SCL, U$3.SCL
SDA: JP4.20, U$1.SDA, U$3.SDA
SLV: JP3.P$3 (3), U$3.L-, U$3.R-

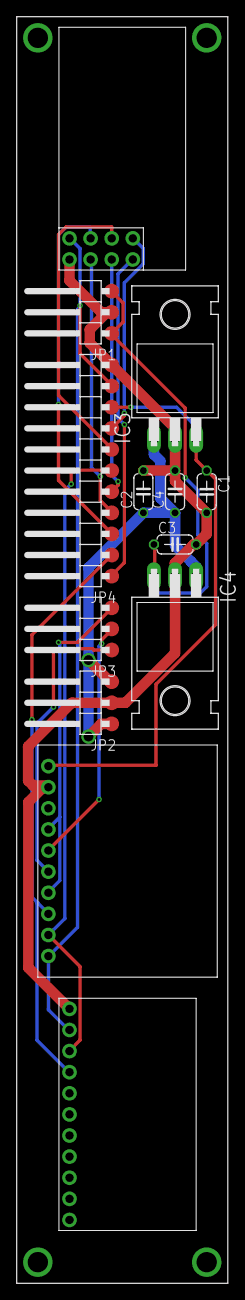
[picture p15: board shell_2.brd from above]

Board: 2 copper layers, 25.4 x 152.4 mm, 13 parts (0 on the bottom side), 16 nets.

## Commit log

2014-09-16 added pdf of schematic
2014-09-21 started external mic board and audio pcb
    [audio.kicad_pcb, audio.sch]
2014-09-21 started pcb design for usb hub
    [usb_hub.kicad_pcb, usb_hub.sch]
2014-09-22 need to not waste as much space on board
    [usb_hub.dsn, usb_hub.kicad_pcb, usb_hub.sch]
2014-09-22 audio pcb updates
    [audio.dsn, audio.kicad_pcb, audio.sch]
2014-09-23 made thinner approx 1x4
    [usb_hub.dsn, usb_hub.kicad_pcb]
2014-09-23 finishing audio pcb layout
    [audio.dsn, audio.kicad_pcb]
2014-09-24 added logo mod, updated audio pcb, and finished micboard
    [audio.kicad_pcb, micboard.sch]
2014-09-24 finished the usb_hub
    [usb_hub.kicad_pcb]
2014-09-25 intial commit for gps module
    [gps.sch]
2014-09-26 updating audio board to change vias
    [audio.dsn, audio.kicad_pcb]
2014-09-26 correcting audio board vias
    [audio.dsn, audio.kicad_pcb, micboard.kicad_pcb]
2014-09-27 now using the SE880 GPS
    [gps.sch]
2014-09-28 finished gps schematic. need to create footprints
    [gps.sch]
2014-09-29 made most of the gps footprints
    [gps.sch]
2014-09-30 usb_hub ready for manufacturing
    [usb_hub.dsn, usb_hub.kicad_pcb]
2014-09-30 finalizing audio board
    [audio.dsn, audio.kicad_pcb, micboard.dsn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]
2014-09-30 usb_hub final. fixed annular ring clearance
    [usb_hub.kicad_pcb]
2014-09-30 moved the trace away from the edge
    [usb_hub.kicad_pcb]
2014-10-01 finished the gps schematic. need to finish BOM. Preliminary work on board
    [gps.kicad_pcb, gps.sch, gps_bom.csv]
2014-10-01 changed mic. board done...i hope
    [audio.dsn, audio.kicad_pcb, audio.sch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]
2014-10-01 board is ready
    [audio.kicad_pcb]
2014-10-04 added jumpers to switch communication method
    [gps.kicad_pcb, gps.sch, gps_bom.csv]
2014-10-06 initial commit of screen schematic
    [screen.sch]
2014-10-07 fixed pin 47 to gnd. need to clip and solder to adjacent pin
    [usb_hub.kicad_pcb, usb_hub.sch]
2014-10-07 need to place all components on bottom and create analog ground plane for antenna
    [gps.kicad_pcb, gps.sch, gps_bom.csv]
2014-10-07 fixed the bom so it shows up nicely
    [gps_bom.csv]
2014-10-07 finishing up schematic and starting board footprints and design
    [screen.kicad_pcb, screen.sch]
2014-10-08 modeled the 50ohm trace as grounded coplanar. need to move things around better so it can solve
    [gps.kicad_pcb]
2014-10-08 finished component modules and started screen board design
    [screen.kicad_pcb, screen.sch]
2014-10-09 moving around some stuff for routing
    [screen.kicad_pcb]
2014-10-11 fixed audio bom
    [audio.csv, audio_bom.csv]
2014-10-11 added usb_hub bom
    [usb_hub.csv, usb_hub_bom.csv]
2014-10-16 finished routing. need to add stitching vias
    [gps.kicad_pcb]
2014-10-17 screen board is complete
    [screen.kicad_pcb]
2014-10-17 added bom
    [screen_bom.csv]
2014-10-19 Finished the GPS module
    [gps.kicad_pcb, gps.sch, gps_bom.csv]
2014-10-19 Finished usb_hub revision B. Less complex, less that can go wrong
    [usb_hub.kicad_pcb, usb_hub.sch, usb_hub_bom.csv]
2014-10-19 started motor driver schematic
    [motor.sch]
2014-10-28 finalizing components for 5v5a
    [powers.sch]
2014-10-28 motor schematic almost finished
    [motor.sch]
2014-11-03 started design for pick and place
    [usb_hub.kicad_pcb, usb_hub.sch]
2014-11-04 Moving all the symbols and footprints in a common library. Changed a few components so we have less reels to buy for pick and place. Changing amplifier to a more supported one from TI.
    [audio.sch, gps.sch, screen.sch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]
2014-11-06 finished routing. need to check bom and trace widths and pos file
    [usb_hub.kicad_pcb, usb_hub.sch]
2014-11-10 usb_hub ready for review. Audio schematic in the works
    [audio.sch, usb_hub.kicad_pcb, usb_hub.sch]
2014-11-10 need to add required fields for assembly
    [audio.sch]
2014-11-11 sent usb_hub for review. Finished gps schematic/bom.
    [gps.kicad_pcb, gps.sch, usb_hub.kicad_pcb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]
2014-11-12 adding fields to audio schematic
    [audio.sch]
2014-11-13 finished schematic. need to route board and send BOM
    [audio.kicad_pcb, audio.sch]
2014-11-14 finished board layout. Ready for review
    [audio.kicad_pcb]
2014-11-14 placed all components on one side to make assembly easier. Ready for review
    [usb_hub.kicad_pcb]
2014-11-14 Need to route the 50ohm trace
    [gps.kicad_pcb, gps.sch]
2014-11-15 cleaned up the usb hub project. waiting quote on elecrow
    [usb_hub.kicad_pcb, usb_hub.sch]
2015-03-20 added eagle files that are used to connect the various store bought breakout boards so that we can finish the project on time
    [core_3.brd, core_3.sch, shell_2.brd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]
